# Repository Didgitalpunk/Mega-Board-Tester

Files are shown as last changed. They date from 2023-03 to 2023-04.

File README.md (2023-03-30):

# Mega-Board-Tester
## An I/O tester made with arduino Uno and arduino mega pinout-compatible boards in mind.
A simple and intuitive microcontroller tester with one LED on each output so you can easiy locate a faulty I/O pin.\
Made for arduino Uno and arduino mega pin-compatible boards (uno, mega, due, leonardo, zero, etc.), but absolutely useable with other boards through jumpers of adapter cables!

https://user-images.githubusercontent.com/29690873/228524618-455ece8d-8ada-4359-9d4d-3bbc245a15be.MOV

## Compatibility
| Board | State |
|---|:--:|
| Mega | 🟢 |
| Leonardo | 🛠️ |
| Uno | 🟢 |
| Zero | 🟢 |

## Usage -- using Version 1 board
1. Upload the file MEGA_board_tester__program.ino to your Arduino.
2. Connect the tester to your board.
3. Watch!

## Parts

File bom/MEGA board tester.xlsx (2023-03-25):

References | type | Value | Quantity | source | price for qty | price*qty*boards
D0, D1, D2, D3, D4, D5, D6, D7, D8, D9, D10, D11, D12, D13, D14, D15, D16, D17, D18, D19, D20, D21, D22, D23, D24, D25, D26, D27, D28, D29, D30, D31, D32, D33, D34, D35, D36, D37, D38, D39, D40, D41, D42, D43, D44, D45, D46, D47, D48, D49, D50, D51, D52, D53, D54, D55, D56, D57, D58, D59, D60, D61, D62, D63, D64, D65, D66, D67, D68, D69 | LED | Green | 70 | PG1112H-TR (https://www.mouser.fr/ProductDetail/Stanley-Electric/PG1112H-TR?qs=byeeYqUIh0Ote1eQCAIB8g%3D%3D) | 17.36 | 45.15 |  | # of boards | 5 | 5-10-15-20 25-30-40-50
D70 | LED | Orange/amber | 1 | AA1112H-TR (https://www.mouser.fr/ProductDetail/Stanley-Electric/AA1112H-TR?qs=byeeYqUIh0N8QKm7cn68qA%3D%3D) | 0.31 | 1.55
D71 | LED | Red | 1 | BR1112H-TR (https://www.mouser.fr/ProductDetail/Stanley-Electric/BR1112H-TR?qs=byeeYqUIh0OasbouIxe83Q%3D%3D) | 0.43 | 2.15
RN1, RN2, RN3, RN4, RN5, RN6, RN7, RN8, RN9, RN10, RN11, RN12, RN13, RN14, RN15, RN16, RN17, RN18 | R_Pack04 | 150ohms | 18 | EXB-S8V151J (https://www.mouser.fr/ProductDetail/Panasonic/EXB-S8V151J?qs=WwqriLBepZusmMZoXctsew%3D%3D) | 8.12 | 40.59
J1 | Arduino Mega Headers | 18x2 header | 1 | SSQ-118-03-G-D (https://www.mouser.fr/ProductDetail/Samtec/SSQ-118-03-G-D?qs=rU5fayqh%252BE2Re4EgOStrbg%3D%3D) | 9.34 | 46.70
 |  | 3x2 header | 1 | SSQ-103-03-G-D (https://www.mouser.fr/ProductDetail/Samtec/SSQ-103-03-G-D?qs=rU5fayqh%252BE2Z%252BZTchcPoHQ%3D%3D) | 2.55 | 12.75
 |  | 8x1 header | 5 | SSQ-108-03-G-S (https://www.mouser.fr/ProductDetail/Samtec/SSQ-108-03-G-S?qs=92ilVni64gxESeLoQPf0Dw%3D%3D) | 13.25 | 63.50
 |  | 10x1 header | 1 | SSQ-110-03-G-S (https://www.mouser.fr/ProductDetail/Samtec/SSQ-110-03-G-S?qs=0u6pJ%2FESxi2TyhdgZpByhg%3D%3D) | 3.32 | 16.60
SW1 | reset switch | smd gull wing push button | 1 | 95cW06D5GWt (https://www.mouser.fr/ProductDetail/706-95CW06D5GWT) | 1.61 | 8.05
PCB | PCB | n/a | 5 | PCB-Way (https://www.pcbway.com/orderonline.aspx?outsideid=7c2974ac-54ad-47d2-8ad7-f6abd25f688f) | 10.73 | 53.65
 |  |  |  |  |  |  | per board price
 |  |  |  | TOTAL | 56.29 | 237.04 | 47.41
 |  |  |  | https://eu.mouser.com/ProjectManager/ProjectDetail.aspx?AccessID=7a8f69fdb1

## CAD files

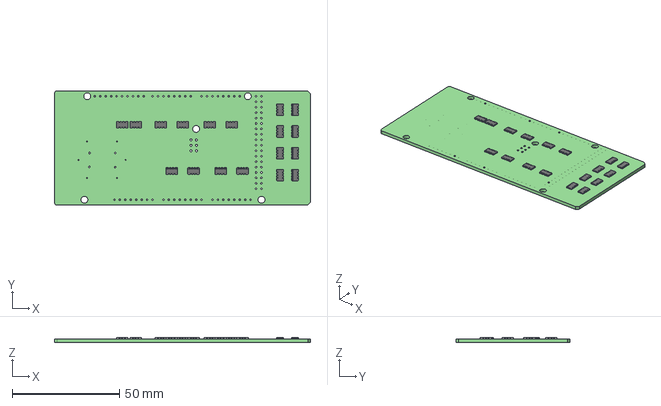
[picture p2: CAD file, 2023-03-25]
MEGA board tester.step
119.4 x 53.3 x 2.20 mm
MEGA board tester PCB

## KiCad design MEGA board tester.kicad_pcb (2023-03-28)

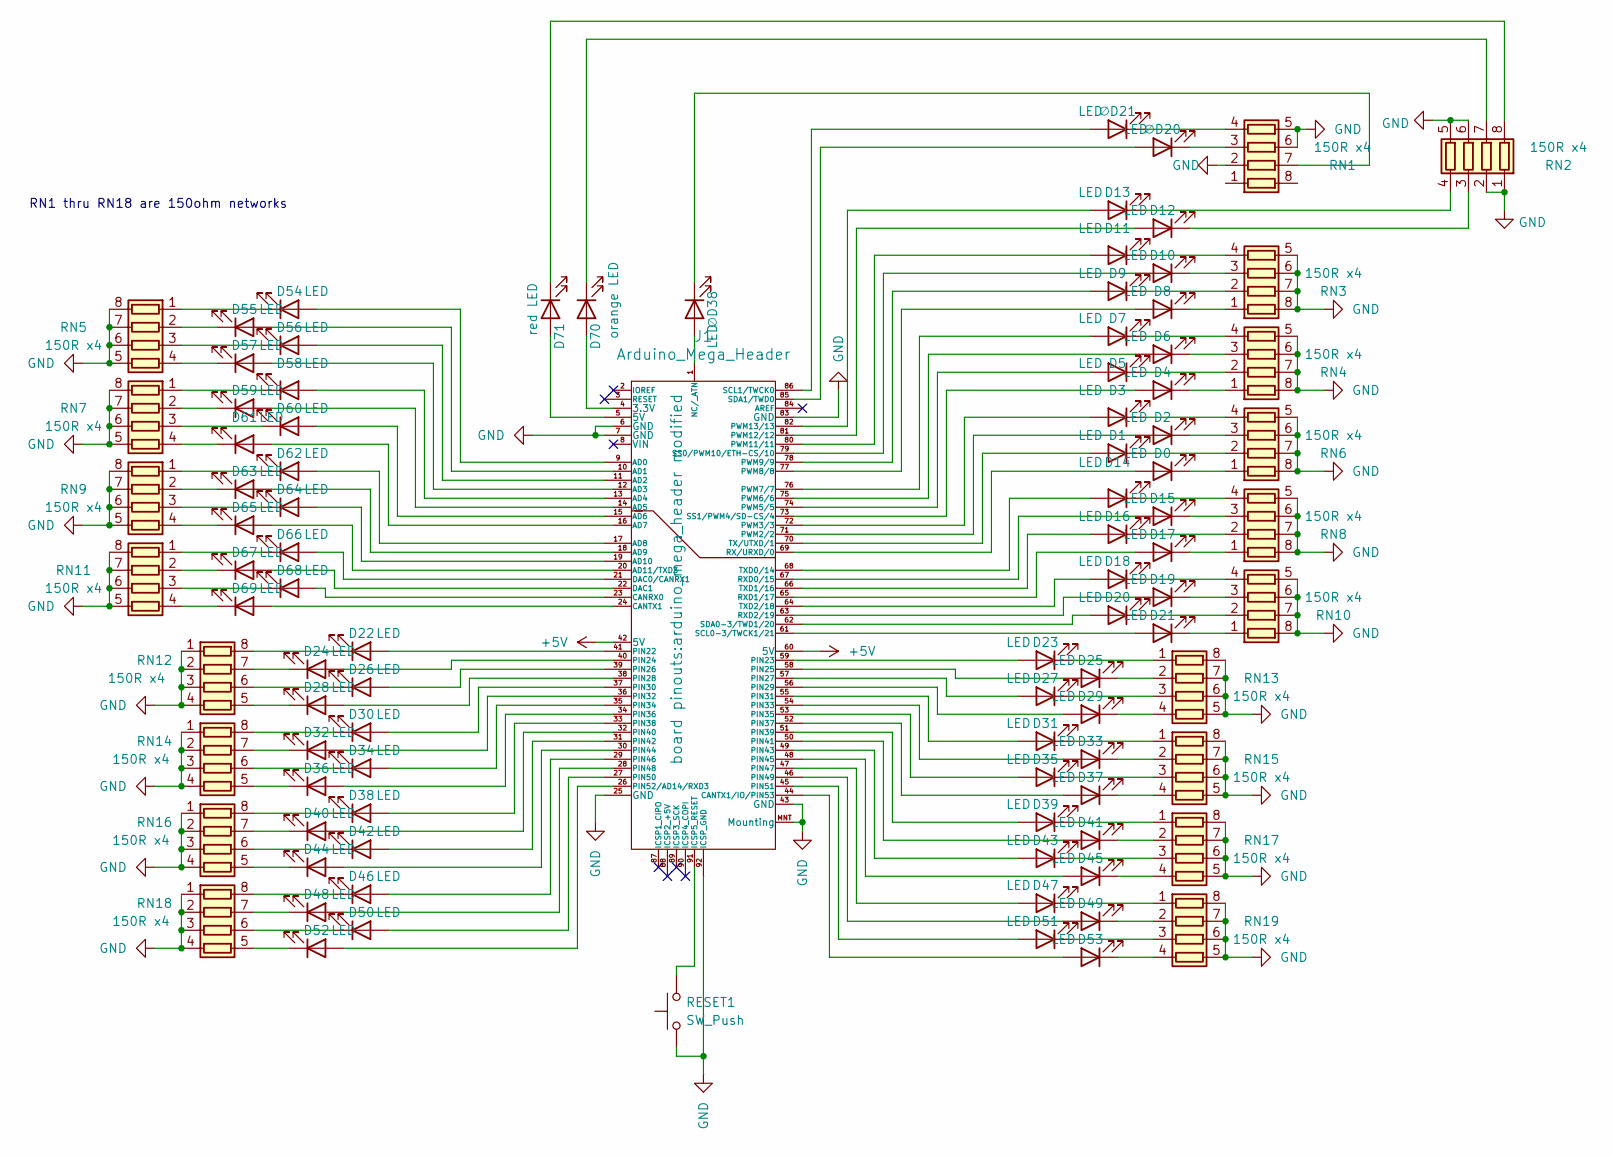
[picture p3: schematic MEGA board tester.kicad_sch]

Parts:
D0, D1, D2, D3, D4, D5, D6, D7, D8, D9, D10, D11, D12, D13, D14, D15, D16, D17, D18, D19, D20, D21, D22, D23, D24, D25, D26, D27, D28, D29, D30, D31, D32, D33, D34, D35, D36, D37, D38, D39, D40, D41, D42, D43, D44, D45, D46, D47, D48, D49, D50, D51, D52, D53, D54, D55, D56, D57, D58, D59, D60, D61, D62, D63, D64, D65, D66, D67, D68, D69: LED; D_0805_2012Metric_Pad1.15x1.40mm_HandSolder
D70: orange LED; D_0805_2012Metric_Pad1.15x1.40mm_HandSolder
D71: red LED; D_0805_2012Metric_Pad1.15x1.40mm_HandSolder
J1: Arduino_Mega_Header; arduino_mega_header modified
RESET1: SW_Push; J-lead grayhill switch
RN1, RN2, RN3, RN4, RN5, RN6, RN7, RN8, RN9, RN10, RN11, RN12, RN13, RN14, RN15, RN16, RN17, RN18, RN19: 150R x4; R_Array_convex_EXB-S8Vxxxx
∅D20, ∅D21, ∅D38: LED; D_0805_2012Metric_Pad1.15x1.40mm_HandSolder

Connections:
+5V: J1.42 (5V), J1.60 (5V)
GND: J1.6 (GND), J1.7 (GND), J1.25 (GND), J1.43 (GND), J1.83 (GND), J1.92 (ICSP_GND), J1.MNT (Mounting), RESET1.1, RN1.2 (R2.1), RN1.5 (R4.2), RN1.6 (R3.2), RN2.1 (R1.1), RN2.2 (R2.1), RN2.5 (R4.2), RN2.6 (R3.2), RN3.5 (R4.2), RN3.6 (R3.2), RN3.7 (R2.2), RN3.8 (R1.2), RN4.5 (R4.2), RN4.6 (R3.2), RN4.7 (R2.2), RN4.8 (R1.2), RN5.5 (R4.2), RN5.6 (R3.2), RN5.7 (R2.2), RN5.8 (R1.2), RN6.5 (R4.2), RN6.6 (R3.2), RN6.7 (R2.2), RN6.8 (R1.2), RN7.5 (R4.2), RN7.6 (R3.2), RN7.7 (R2.2), RN7.8 (R1.2), RN8.5 (R4.2), RN8.6 (R3.2), RN8.7 (R2.2), RN8.8 (R1.2), RN9.5 (R4.2), RN9.6 (R3.2), RN9.7 (R2.2), RN9.8 (R1.2), RN10.5 (R4.2), RN10.6 (R3.2), RN10.7 (R2.2), RN10.8 (R1.2), RN11.5 (R4.2), RN11.6 (R3.2), RN11.7 (R2.2), RN11.8 (R1.2), RN12.1 (R1.1), RN12.2 (R2.1), RN12.3 (R3.1), RN12.4 (R4.1), RN13.5 (R4.2), RN13.6 (R3.2), RN13.7 (R2.2), RN13.8 (R1.2), RN14.1 (R1.1), RN14.2 (R2.1), RN14.3 (R3.1), RN14.4 (R4.1), RN15.5 (R4.2), RN15.6 (R3.2), RN15.7 (R2.2), RN15.8 (R1.2), RN16.1 (R1.1), RN16.2 (R2.1), RN16.3 (R3.1), RN16.4 (R4.1), RN17.5 (R4.2), RN17.6 (R3.2), RN17.7 (R2.2), RN17.8 (R1.2), RN18.1 (R1.1), RN18.2 (R2.1), RN18.3 (R3.1), RN18.4 (R4.1), RN19.5 (R4.2), RN19.6 (R3.2), RN19.7 (R2.2), RN19.8 (R1.2); also elsewhere on the board
unnamed: D0.1 (K), RN6.1 (R1.1)
unnamed: D0.2 (A), J1.69 (RX/URXD/0)
unnamed: D1.1 (K), RN6.2 (R2.1)
unnamed: D1.2 (A), J1.70 (TX/UTXD/1)
unnamed: D2.1 (K), RN6.3 (R3.1)
unnamed: D2.2 (A), J1.71 (PWM2/2)
unnamed: D3.1 (K), RN6.4 (R4.1)
unnamed: D3.2 (A), J1.72 (PWM3/3)
unnamed: D4.1 (K), RN4.1 (R1.1)
unnamed: D4.2 (A), J1.73 (SS1/PWM4/SD-CS/4)
unnamed: D5.1 (K), RN4.2 (R2.1)
unnamed: D5.2 (A), J1.74 (PWM5/5)
unnamed: D6.1 (K), RN4.3 (R3.1)
unnamed: D6.2 (A), J1.75 (PWM6/6)
unnamed: D7.1 (K), RN4.4 (R4.1)
unnamed: D7.2 (A), J1.76 (PWM7/7)
unnamed: D8.1 (K), RN3.1 (R1.1)
unnamed: D8.2 (A), J1.77 (PWM8/8)
unnamed: D9.1 (K), RN3.2 (R2.1)
unnamed: D9.2 (A), J1.78 (PWM9/9)
unnamed: D10.1 (K), RN3.3 (R3.1)
unnamed: D10.2 (A), J1.79 (SS0/PWM10/ETH-CS/10)
unnamed: D11.1 (K), RN3.4 (R4.1)
unnamed: D11.2 (A), J1.80 (PWM11/11)
unnamed: D12.1 (K), RN2.3 (R3.1)
unnamed: D12.2 (A), J1.81 (PWM12/12)
unnamed: D13.1 (K), RN2.4 (R4.1)
unnamed: D13.2 (A), J1.82 (PWM13/13)
unnamed: D14.1 (K), RN8.4 (R4.1)
unnamed: D14.2 (A), J1.68 (TXD0/14)
unnamed: D15.1 (K), RN8.3 (R3.1)
unnamed: D15.2 (A), J1.67 (RXD0/15)
unnamed: D16.1 (K), RN8.2 (R2.1)
unnamed: D16.2 (A), J1.66 (TXD1/16)
unnamed: D17.1 (K), RN8.1 (R1.1)
unnamed: D17.2 (A), J1.65 (RXD1/17)
unnamed: D18.1 (K), RN10.4 (R4.1)
unnamed: D18.2 (A), J1.64 (TXD2/18)
unnamed: D19.1 (K), RN10.3 (R3.1)
unnamed: D19.2 (A), J1.63 (RXD2/19)
unnamed: D20.1 (K), RN10.2 (R2.1)
unnamed: D20.2 (A), J1.62 (SDA0-3/TWD1/20)
unnamed: D21.1 (K), RN10.1 (R1.1)
unnamed: D21.2 (A), J1.61 (SCL0-3/TWCK1/21)
unnamed: D22.1 (K), RN12.8 (R1.2)
unnamed: D22.2 (A), J1.41 (PIN22)
unnamed: D23.1 (K), RN13.1 (R1.1)
unnamed: D23.2 (A), J1.59 (PIN23)
unnamed: D24.1 (K), RN12.7 (R2.2)
unnamed: D24.2 (A), J1.40 (PIN24)
unnamed: D25.1 (K), RN13.2 (R2.1)
unnamed: D25.2 (A), J1.58 (PIN25)
unnamed: D26.1 (K), RN12.6 (R3.2)
unnamed: D26.2 (A), J1.39 (PIN26)
unnamed: D27.1 (K), RN13.3 (R3.1)
unnamed: D27.2 (A), J1.57 (PIN27)
unnamed: D28.1 (K), RN12.5 (R4.2)
unnamed: D28.2 (A), J1.38 (PIN28)
unnamed: D29.1 (K), RN13.4 (R4.1)
unnamed: D29.2 (A), J1.56 (PIN29)
unnamed: D30.1 (K), RN14.8 (R1.2)
unnamed: D30.2 (A), J1.37 (PIN30)
unnamed: D31.1 (K), RN15.1 (R1.1)
unnamed: D31.2 (A), J1.55 (PIN31)
unnamed: D32.1 (K), RN14.7 (R2.2)
unnamed: D32.2 (A), J1.36 (PIN32)
unnamed: D33.1 (K), RN15.2 (R2.1)
unnamed: D33.2 (A), J1.54 (PIN33)
unnamed: D34.1 (K), RN14.6 (R3.2)
unnamed: D34.2 (A), J1.35 (PIN34)
unnamed: D35.1 (K), RN15.3 (R3.1)
unnamed: D35.2 (A), J1.53 (PIN35)
unnamed: D36.1 (K), RN14.5 (R4.2)
unnamed: D36.2 (A), J1.34 (PIN36)
unnamed: D37.1 (K), RN15.4 (R4.1)
unnamed: D37.2 (A), J1.52 (PIN37)
unnamed: D38.1 (K), RN16.8 (R1.2)
unnamed: D38.2 (A), J1.33 (PIN38)
unnamed: D39.1 (K), RN17.1 (R1.1)
unnamed: D39.2 (A), J1.51 (PIN39)
unnamed: D40.1 (K), RN16.7 (R2.2)
unnamed: D40.2 (A), J1.32 (PIN40)
unnamed: D41.1 (K), RN17.2 (R2.1)
unnamed: D41.2 (A), J1.50 (PIN41)
unnamed: D42.1 (K), RN16.6 (R3.2)
unnamed: D42.2 (A), J1.31 (PIN42)
unnamed: D43.1 (K), RN17.3 (R3.1)
unnamed: D43.2 (A), J1.49 (PIN43)
unnamed: D44.1 (K), RN16.5 (R4.2)
unnamed: D44.2 (A), J1.30 (PIN44)
unnamed: D45.1 (K), RN17.4 (R4.1)
unnamed: D45.2 (A), J1.48 (PIN45)
unnamed: D46.1 (K), RN18.8 (R1.2)
unnamed: D46.2 (A), J1.29 (PIN46)
unnamed: D47.1 (K), RN19.1 (R1.1)
unnamed: D47.2 (A), J1.47 (PIN47)
unnamed: D48.1 (K), RN18.7 (R2.2)
unnamed: D48.2 (A), J1.28 (PIN48)
unnamed: D49.1 (K), RN19.2 (R2.1)
unnamed: D49.2 (A), J1.46 (PIN49)
unnamed: D50.1 (K), RN18.6 (R3.2)
unnamed: D50.2 (A), J1.27 (PIN50)
unnamed: D51.1 (K), RN19.3 (R3.1)
unnamed: D51.2 (A), J1.45 (PIN51)
unnamed: D52.1 (K), RN18.5 (R4.2)
unnamed: D52.2 (A), J1.26 (PIN52/AD14/RXD3)
unnamed: D53.1 (K), RN19.4 (R4.1)
unnamed: D53.2 (A), J1.44 (CANTX1/IO/PIN53)
unnamed: D54.1 (K), RN5.1 (R1.1)
unnamed: D54.2 (A), J1.9 (AD0)
unnamed: D55.1 (K), RN5.2 (R2.1)
unnamed: D55.2 (A), J1.10 (AD1)
unnamed: D56.1 (K), RN5.3 (R3.1)
unnamed: D56.2 (A), J1.11 (AD2)
unnamed: D57.1 (K), RN5.4 (R4.1)
unnamed: D57.2 (A), J1.12 (AD3)
unnamed: D58.1 (K), RN7.1 (R1.1)
unnamed: D58.2 (A), J1.13 (AD4)
unnamed: D59.1 (K), RN7.2 (R2.1)
unnamed: D59.2 (A), J1.14 (AD5)
unnamed: D60.1 (K), RN7.3 (R3.1)
unnamed: D60.2 (A), J1.15 (AD6)
unnamed: D61.1 (K), RN7.4 (R4.1)
unnamed: D61.2 (A), J1.16 (AD7)
unnamed: D62.1 (K), RN9.1 (R1.1)
unnamed: D62.2 (A), J1.17 (AD8)
unnamed: D63.1 (K), RN9.2 (R2.1)
unnamed: D63.2 (A), J1.18 (AD9)
unnamed: D64.1 (K), RN9.3 (R3.1)
unnamed: D64.2 (A), J1.19 (AD10)
unnamed: D65.1 (K), RN9.4 (R4.1)
unnamed: D65.2 (A), J1.20 (AD11/TXD3)
unnamed: D66.1 (K), RN11.1 (R1.1)
unnamed: D66.2 (A), J1.21 (DAC0/CANRX1)
unnamed: D67.1 (K), RN11.2 (R2.1)
unnamed: D67.2 (A), J1.22 (DAC1)
unnamed: D68.1 (K), RN11.3 (R3.1)
unnamed: D68.2 (A), J1.23 (CANRX0)
unnamed: D69.1 (K), RN11.4 (R4.1)
unnamed: D69.2 (A), J1.24 (CANTX1)
unnamed: D70.1 (K), RN2.7 (R2.2)
unnamed: D70.2 (A), J1.4 (3.3V)
unnamed: D71.1 (K), RN2.8 (R1.2)
unnamed: D71.2 (A), J1.5 (5V)
unnamed: J1.1 (NC/_ATN), ∅D38.2 (A)
unnamed: J1.85 (SDA1/TWD0), ∅D20.2 (A)
unnamed: J1.86 (SCL1/TWCK0), ∅D21.2 (A)
unnamed: J1.91 (ICSP5_RESET), RESET1.2
unnamed: RN1.3 (R3.1), ∅D20.1 (K)
unnamed: RN1.4 (R4.1), ∅D21.1 (K)
unnamed: RN1.7 (R2.2), ∅D38.1 (K)

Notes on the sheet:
RN1 thru RN18 are 150ohm networks

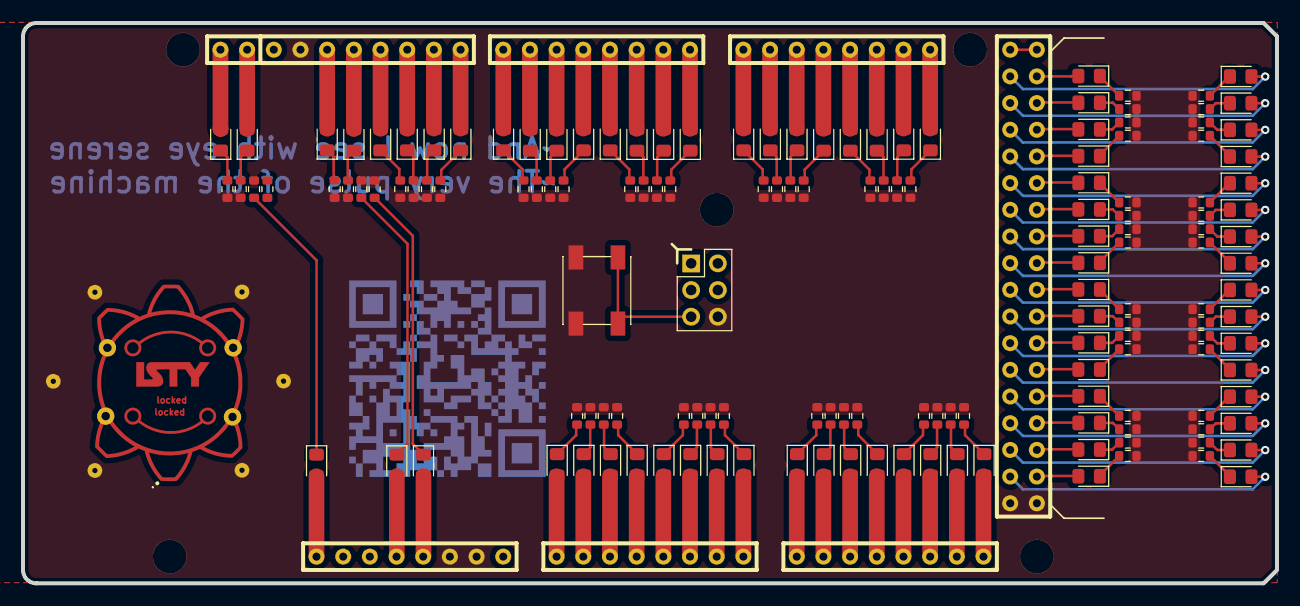
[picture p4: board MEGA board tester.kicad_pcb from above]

Board: 2 copper layers, 119.4 x 53.3 mm, 97 parts (0 on the bottom side), 153 nets.

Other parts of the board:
Logo1: ISTY LOGO FOR MEGA TEST BOARD 2

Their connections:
GND: Logo1.2; also elsewhere on the board

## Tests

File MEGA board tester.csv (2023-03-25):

Id;"Designator";"Package";"Quantity";"Designation";"Supplier and ref";
1;"D39 | D9 | D53 | D37 | D10 | D16 | D36 | D54 | D15 | D1 | D35 | D44 | D49 | D60 | D0 | D38 | D42 | D52 | D7 | D23 | D5 | D58 | D57 | D62 | D33 | D69 | D34 | D43 | D8 | D45 | D48 | D50 | D21 | D2 | D19 | D31 | D66 | D28 | D22 | D59 | D27 | D3 | D40 | D17 | D65 | D20 | D64 | D32 | D41 | D56 | D4 | D68 | D47 | D12 | D67 | D61 | D24 | D46 | D18 | D63
2;"RN16 | RN6 | RN14 | RN11 | RN4 | RN13 | RN17 | RN15 | RN8 | RN5 | RN9 | RN12 | RN7 | RN10 | RN2";"R_Array_Convex_4x1206";15;"R_Pack04";;;
3;"J1";"arduino_mega_header modified";1;"Arduino_Mega_Header";;;
4;"RN3 | RN1";"R_Array_Convex_5x1206";2;"R_Pack05";;;
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

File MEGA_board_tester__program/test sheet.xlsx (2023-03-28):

pin lit | 1 | 2 | 3 | 4 | 5 | 6 | 7 | 8 | 9 | 10 | 11 | 12 | 13 | 14 | 15 | 16 | 17 | 18 | 19 | 20 | 21 | 22 | 23 | 24 | 25 | 26 | 27 | 28 | 29 | 30 | 31 | 32 | 33 | 34 | 35 | 36 | 37 | 38 | 39 | 40 | 41 | 42 | 43 | 44 | 45 | 46 | 47 | 48 | 49 | 50 | 51 | 52 | 53 | 54 | 55 | 56 | 57 | 58 | 59
1 | ●
2 |  | ● |  |  |  |  |  |  |  |  |  |  |  |  |  |  |  |  |  |  |  |  |  |  |  |  |  |  |  | ●
3 |  |  | ●
4 |  |  |  | ●
5 |  |  |  |  | ●
6 |  |  |  |  |  | ●
7 |  |  |  |  |  |  | ●
8 |  |  |  |  |  |  |  | ● |  |  |  |  |  |  |  |  |  |  |  |  |  |  |  |  |  |  |  |  | ● |  |  |  |  |  |  |  |  |  |  |  |  |  |  |  | ●
9 |  |  |  |  |  |  |  |  | ● |  |  |  |  |  |  |  |  |  |  |  |  |  |  |  |  |  |  |  | ● |  |  |  |  |  |  |  |  |  |  |  |  |  |  |  | ●
10 |  |  |  |  |  |  |  |  |  | ● |  |  |  |  |  |  |  |  |  |  |  |  |  |  |  |  |  |  |  |  |  |  |  |  |  |  |  |  |  |  |  |  |  |  | ●
11 |  |  |  |  |  |  |  |  |  |  | ● |  |  |  |  |  |  |  |  |  |  |  |  |  |  |  |  |  |  |  |  |  |  |  |  |  |  |  |  |  |  |  |  |  | ●
12 |  |  |  |  |  |  |  |  |  |  |  | ●
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

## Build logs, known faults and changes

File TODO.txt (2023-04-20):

- align pin numbering on the board to be the same as the arduino Mega.
- make it so there is a legend at least every few LEDs for the big connector, it's a pain to use right now.
- upload AVR dumps from flipper of boards that have the program in them.
-- link to (future) Flipper ICSP/SPI/TxRx breakout board

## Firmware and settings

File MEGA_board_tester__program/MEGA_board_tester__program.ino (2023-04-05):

//Version 1.2.1    3/27/2023
//Credits to Freya Mutschler and Diana N. Corsten

constexpr auto MIN = 0;

#if defined(__AVR_ATmega328P__)
constexpr auto MAX = 19;
constexpr auto Shift = 4;
constexpr auto Delay = 100;
int pins[MAX+1] = {  7, 6, 5, 4, 3, 2, 1, 0, 19, 18, 17, 16, 15, 14, 13, 12 , 11, 10, 9, 8 };
#endif

#if defined(__AVR_ATmega1280__) || defined(__AVR_ATmega2560__) || defined(__AVR_ATmega1284__) || defined(__AVR_ATmega1284P__) || defined(__AVR_ATmega644__) || defined(__AVR_ATmega644A__) || defined(__AVR_ATmega644P__) || defined(__AVR_ATmega644PA__)
constexpr auto MAX = 69;
constexpr auto Shift = 6;
constexpr auto Delay = 75;
const int pins[MAX+1] = {
13, 12, 11, 10, 9, 8, 7, 6, 5, 4, 3, 2,
1, 0, 14, 15, 16, 17, 18, 19,
20, 21, 22, 23, 24, 25, 26, 27, 28, 29,
30, 31, 32, 33, 34, 35, 36, 37, 38, 39,
40, 41, 42, 43, 44, 45, 46, 47, 48, 49,
50, 51, 52, 53,
69, 68, 67, 66, 65, 64,
63, 62, 61, 60, 59, 58, 57, 56, 55, 54};
#endif

#if defined(__AVR_ATmega32U4__) || defined(__AVR_ATmega16U4__)
//arduino Leonardo
#endif


#if defined(?)
//arduino Zero
constexpr auto MAX = 21;
constexpr auto Shift = 4;
constexpr auto Delay = 100;
int pins[MAX+1] = { 21, 20, 13, 12 , 11, 10, 9, 8, 7, 6, 5, 4, 3, 2, 1, 0, 19, 18, 17, 16, 15, 14 };
#endif

int decrement(int val, int dec) {
    return ((val - dec - MIN) % (MAX - MIN + 1) + (MAX - MIN + 1)) % (MAX - MIN + 1) + MIN;
}

void setup() {
   for(int i; i <= MAX; i++){
        digitalWrite(pins[i], LOW);
        pinMode(pins[i], OUTPUT);
    }
}

void loop() {
int  x = 0;
  for (x = MIN; x <= MAX; x++) {
    digitalWrite(pins[decrement(x,Shift)], LOW);
    digitalWrite(pins[x], HIGH);
    delay(Delay);
  }
  
}

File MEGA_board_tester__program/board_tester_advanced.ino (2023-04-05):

// And now I see with eye serene, the very pulse of the machine

// Arduino Board Tester Program Version 2.1 April 5 2023 
// Design and Fabrication by Freya Mutschler
// Code by Diana N. Corsten and Freya Mutschler

// This is a far more advanced version of the same program, with added features that can be used if you wish to perform other tests.
// In this version, the pin on the board is represented by an object of type Pin that is capable of performing all sorts of math.
// If you simply wish to test if all the pins on your board are working, the regular program will serve you just as well. 


constexpr auto MIN = 0;

#if defined(__AVR_ATmega328P__)
// Arduino Uno (R1, R2, R3), Arduino Nano 
constexpr auto MAX = 19;
constexpr auto SHIFT = 4;
constexpr auto DELAY = 100;
int pins[MAX+1] = {  7, 6, 5, 4, 3, 2, 1, 0, 19, 18, 17, 16, 15, 14, 13, 12 , 11, 10, 9, 8 };

#elif defined(__AVR_ATmega1280__) || defined(__AVR_ATmega2560__) || defined(__AVR_ATmega1284__) || defined(__AVR_ATmega1284P__) || defined(__AVR_ATmega644__) || defined(__AVR_ATmega644A__) || defined(__AVR_ATmega644P__) || defined(__AVR_ATmega644PA__)
// Arduino Mega
constexpr auto MAX = 69;
constexpr auto SHIFT = 6;
constexpr auto DELAY = 75;
const int pins[MAX+1] = {
13, 12, 11, 10, 9, 8, 7, 6, 5, 4, 3, 2,
1, 0, 14, 15, 16, 17, 18, 19,
20, 21, 22, 23, 24, 25, 26, 27, 28, 29,
30, 31, 32, 33, 34, 35, 36, 37, 38, 39,
40, 41, 42, 43, 44, 45, 46, 47, 48, 49,
50, 51, 52, 53,
69, 68, 67, 66, 65, 64,
63, 62, 61, 60, 59, 58, 57, 56, 55, 54};

#elif defined(__AVR_ATmega32U4__) || defined(__AVR_ATmega16U4__)
//Arduino Leonardo, not yet implemented

#elif defined(NYI)
// Arduino Zero, not yet implemented
constexpr auto MAX = 21;
constexpr auto SHIFT = 4;
constexpr auto DELAY = 100;
int pins[MAX+1] = { 21, 20, 13, 12 , 11, 10, 9, 8, 7, 6, 5, 4, 3, 2, 1, 0, 19, 18, 17, 16, 15, 14 };
#endif

class Pin{
    int _num; 

public:
    // Constructors
    Pin() { _num = MIN; }
    Pin(unsigned num) {
		if (num <= MAX && num >= MIN) { _num = num; } // Incorrect initialization via assignment is handled by setting _num to MIN and then adding the incorrect assignment
		else { _num = MIN; this->operator+=(num); }    
	}
    Pin(const Pin& otherpin) : _num(otherpin._num) {} 
    
    // Int Conversion
    operator int() { return _num; }
    
    // Operators
    bool operator == (const Pin& otherpin) const { return this->_num == otherpin._num; }
	bool operator == (const int rhs) const { return _num == rhs; }
    
    Pin& operator = (const Pin& otherpin) {
		if (this != &otherpin) { _num = otherpin._num; } 
		return *this;
	}

    Pin& operator =(int set) {
		if (set != this->_num) {
			if (set <= MAX && set >= MIN) { _num = set; } 
			else { _num = MIN; return this->operator+=(set); } // incorrect assignment is handled by setting _num to MIN and then adding the incorrect assignment, thus producing a valid result
		}
		return *this;
	}

    Pin& operator +=(int add) {
		if (add != 0) {
			if (add < 0) { return this->operator-=(abs(add)); } // attempting to use a negative number will simply invoke the - operator
			_num = (_num + add - MIN) % (MAX - MIN + 1) + MIN;
		}
		return *this;
	}

    Pin& operator -=(int sub) {
		if (sub != 0) {
			if (sub < 0) { return this->operator+=(abs(sub)); } // attempting to use a negative number will simply invoke the += operator
			_num = ((_num - sub - MIN) % (MAX - MIN + 1) + (MAX - MIN + 1)) % (MAX - MIN + 1) + MIN; // The % operator can not handle negatives like it does overflowing positives,
		}                                                                                            // so this part looks a lot more complicated.       
		return *this;                                                                                // The added complexity of `+/- MIN` is to ensure that MIN != 0 would still produce       
	}                                                                                                    // the desired results.
    	int operator-(int sub) {
        return ((_num - sub - MIN) % (MAX - MIN + 1) + (MAX - MIN + 1)) % (MAX - MIN + 1) + MIN;
    }
    	int operator+(int add) {
        return (_num + add - MIN) % (MAX - MIN + 1) + MIN;
    }
	
	Pin& operator++() { 
        _num = _num == MAX ? MIN : _num + 1;
        return *this;
	}

	Pin operator++(int) { 
		Pin temp(*this);
		_num = _num == MAX ? MIN : _num + 1;
		return temp;
	}

    Pin& operator --() {
            _num = _num == MIN ? MAX : _num - 1;
            return *this;
	}

    Pin operator --(int) {
            Pin temp(*this);
            _num = _num == MIN ? MAX : _num - 1;
            return temp;
	}
};

void setup(){
    
    for(int i; i <= MAX; i++){
        pinMode(pins[i], OUTPUT);
        digitalWrite(pins[i], LOW);
    }
}

void loop(){

    Pin p1;
    for(p1 = MIN; p1 <= MAX; p1++){
               
        digitalWrite(pins[p1 - SHIFT], LOW);
        digitalWrite(pins[p1], HIGH);
        delay(DELAY);
        if(p1 == MAX) {break;}

    }

}

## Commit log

2023-03-25 Add files via upload
    initial commit:
    - V1 board and layout, boards received and functional after assembly.
    - V1 code, functional.
    - bom folder has the datasheets for the components used on the board
    -all components bought from Mouser (no affiliation) and boards fab'd by PCBway (no affiliation)
    [MEGA board tester-B_Cu.gbr, MEGA board tester-B_Mask.gbr, MEGA board tester-B_Paste.gbr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]
2023-03-25 PCB, schematic, and code update
    PCB update:
    - removed the rising sung logo as it was not fab-friendly (was removed by the fab-house from the fab'd PCB)
    - updated version to 1.1
    - added version and date on User.Drawing layer
    - there is a known problem where the data transmission will not happen on arduino if the test board is plugged in, due to pins 0 and 1 (D0 & D1) being used by the board tester. Only (untested) fix for now is to disconnect those two paths from ground by either not populating the pins, or cutting the traces at any point before RN5).
    Schematic:
    - cleanup. added '150R x4' as value to the resistor networks in place of 'Rpack04'
    Code:
    - cleanup
    - added bit of code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
    [MEGA board tester.kicad_pcb, MEGA board tester.kicad_sch]
2023-03-25 Delete MEGA board tester - testing program directory
    renamed the files and directory.
2023-03-25 Delete MEGA board tester-backups directory
    not needed for the repo.
2023-03-25 added beta.ccp as an arduino program
2023-03-25 removed beta.ino, beta.cpp, and pushed Mega_board_tester__program to V1.2, with board detection! only uno and mega board for now, more will come.
2023-03-28 PCB updated to version 2 added ∅D20, ∅D21, ∅D38, to ensure compatibility with Arduino Zero boards. (D38 is called ANT on the board, unnamed on mega and unoR3) moved the ISTY logo and credits to make 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
    have yet to decide on what to do with D0 and D1 so they don't interfere with program upload. leave them? remove them and put in test loops for probing? tbd.
    [MEGA board tester.kicad_pcb, MEGA board tester.kicad_sch, test sheet.xlsx]
2023-03-29 updated readme
    updated short description to be a bit more accurate,
    updated long descriptions to talk about other non-pin-compatible boards
    changed usage to reflect current PCB version (version 1)
    Thanks to Normanalie for creating the README !
2023-03-30 Program Version 2 added, Program V 1.2.1 fixed
    [board_tester_v2.ino]
2023-03-30 File name errors corrected
    [MEGA_board_tester__program.ino]
2023-03-30 Update board_tester_v2.ino
    updated postfix operators to be in line with standard practice
2023-04-05 Update board_tester_v2.ino
    fixed + and - operators to perform arithmetic without modifying the object. To actually modify the object, call the += or -= operators.
    [board_tester_v2.ino]
2023-04-05 Update board_tester_v2.ino
    forgot an = sign
2023-04-05 Update and rename board_tester_v2.ino to board_tester_advanced.ino
2023-04-20 Create TODO.txt
    created TODO file for the next steps in board amelioration.
